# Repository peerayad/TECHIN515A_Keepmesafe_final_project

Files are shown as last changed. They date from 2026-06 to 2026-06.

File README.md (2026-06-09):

# KeepMeSafe — GuardianPod Room Security System

An embedded AI-powered room security system built on the Seeed XIAO ESP32-S3. It detects intruders using a PIR sensor + camera + on-device ML inference (Edge Impulse), then sends an alert with a rotated image to Firebase Realtime Database. A live web dashboard displays alerts in real time.

---

## System Architecture

```
[PIR Sensor] → [ESP32-S3] → [ML Inference (Edge Impulse)]
                   │                      │
              [OV2640 Camera]        Person detected?
                                          │
                              ┌───────────┴───────────┐
                           WiFi ON                 WiFi OFF
                              │                        │
                       [Firebase RTDB]            [SD Card]
                              │
                       [Web Dashboard]
                    keepmesafe-1e248.web.app
```

---

## Hardware Requirements

| Component | Model | Pin |
|---|---|---|
| Microcontroller | Seeed XIAO ESP32-S3 | — |
| Camera | OV2640 (built-in) | — |
| PIR Sensor | Any 3.3V PIR | D0 |
| Buzzer | Active/Passive buzzer | D3 |
| Button A | Tactile button | D6 |
| Button B | Tactile button | D7 |
| OLED Display | SSD1306 128×64 I2C | SDA=D4, SCL=D5 |
| SD Card Module | SPI | CS=D21 |

---

## Software Requirements

### Firmware (ESP32)
- [PlatformIO](https://platformio.org/) with VS Code extension
- Arduino framework for ESP32

### Libraries (auto-installed via `platformio.ini`)
- `Adafruit SSD1306`
- `Adafruit GFX Library`
- `WiFiManager @ ^2.0.17`
- `FirebaseClient @ ^1.5.0`

### Manual Library (place in `/lib`)
- `ML_Camera_inferencing` — Edge Impulse exported library (person detection model)

---

## Firebase Setup

1. Go to [Firebase Console](https://console.firebase.google.com) and create a project (or use existing `keepmesafe-1e248`)
2. Enable **Realtime Database** (start in test mode)
3. Set database rules to allow read/write:
```json
{
  "rules": {
    ".read": true,
    ".write": true
  }
}
```
4. Copy your Firebase config values into `src/main.cpp`:
```cpp
#define FIREBASE_DATABASE_URL "https://your-project-default-rtdb.firebaseio.com"
#define ROOM_ID               "room304"
```

---

## Project Structure

```
keepmesafe_SIT/
├── src/
│   └── main.cpp          # Main firmware
├── lib/
│   └── ML_Camera_inferencing/  # Edge Impulse model library
├── test/
│   └── index.html        # Web dashboard
├── platformio.ini         # PlatformIO config
└── README.md
```

---

## How to Run the Firmware

### 1. Clone / open the project
Open the project folder in VS Code with PlatformIO installed.

### 2. Install dependencies
PlatformIO will auto-install all libraries listed in `platformio.ini` on first build.  
Make sure the Edge Impulse `ML_Camera_inferencing` library is placed in `/lib`.

### 3. Build & Upload
```bash
# Build only
pio run

# Build and upload to device
pio run --target upload

# Open Serial Monitor
pio device monitor --baud 115200
```
Or use the PlatformIO buttons in VS Code (✓ Build / → Upload).

### 4. First Boot — Choose Mode
On startup the OLED will show:
```
Connect WiFi?
A: Connect WiFi
B: SD Card mode
Waiting...
```
- Press **A** → connects to saved WiFi (or opens WiFiManager portal `KeepMeSafe` / password `12345678`)
- Press **B** → offline SD Card mode

---

## How to Run the Web Dashboard

### Option 1 — Local (quick test)
```bash
# In the test/ folder
cd test
python3 -m http.server 8080
```
Then open `http://localhost:8080`

### Option 2 — Firebase Hosting (public URL)
```bash
# Install Firebase CLI
npm install -g firebase-tools

# Login
firebase login

# From project root
firebase init hosting
# → Select project: keepmesafe-1e248
# → Public directory: test
# → Single-page app: No
# → Overwrite index.html: No

# Deploy
firebase deploy --only hosting
```
Live at: `https://keepmesafe-1e248.web.app`

---

## Detection Pipeline

```
PIR triggered
    ↓
Confirm: ≥ 3 triggers in 3 seconds
    ↓
Capture 3 frames (100ms apart)
    ↓ per frame:
  decode JPEG → RGB888
  rotate 90° CCW (portrait)
  resize to EI input size
  auto-contrast normalization
  contrast boost (×1.3)
  Edge Impulse classifier
    ↓
Majority vote: ≥ 2/3 = PERSON
    ↓
Rotate final frame 90° CCW
    ↓
WiFi? → Firebase (base64 JPEG + metadata)
No WiFi? → SD Card (JPEG file)
    ↓
ALARM! — River Flows in You
Press B to cancel
```

---

## Button Controls

| Button | Context | Action |
|---|---|---|
| **A** | Startup | Connect WiFi |
| **B** | Startup | SD Card mode |
| **A** | Standby | Open Settings menu |
| **A** | Settings | Select / navigate |
| **B** | Settings | Next item / exit |
| **B** | Alarm | Cancel alarm immediately |

### Settings Menu
```
SETTINGS
> Mode        ← A to enter
  Sound
A:Select  B:Next/Exit
```
- **Mode** — Switch between WiFi and SD Card mode
- **Sound** — Toggle buzzer ON/OFF

---

## Web Dashboard Features

| Tab | Description |
|---|---|
| **Home** | Live status (SECURED/ALERT), latest snapshot, alert number, time |
| **History** | Last 20 alerts as gallery — click to view full image + time |

---

## Key Configuration

All in `src/main.cpp`:

```cpp
#define PERSON_THRESHOLD  0.5f    // ML confidence threshold (0.0–1.0)
#define CAPTURE_COOLDOWN  10000   // ms between detections
#define ROOM_ID           "room304"

const float alpha = 1.3f;        // Contrast boost multiplier
// personVotes >= 2               // Votes needed out of 3
```

---

## Troubleshooting

| Issue | Cause | Fix |
|---|---|---|
| OLED upside down | Enclosure orientation | `display.setRotation(2)` already applied |
| Firebase not connecting | Rules expired | Set rules `.read/.write = true` |
| Website shows no data | Opened as `file://` | Serve via localhost or Firebase Hosting |
| Image sideways on website | Rotation mismatch | 90° CCW applied automatically in firmware |
| Alert numbers jumping | PIR false triggers | Cooldown reset after each detection |
| Alarm won't stop | — | Press Button B |

---

## License

Built for SIT (School of Information Technology) project — GuardianPod v1.0

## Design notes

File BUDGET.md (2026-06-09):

# Budget Update

| Item | Qty | Unit Price | Total | Source |
|---|---|---|---|---|
| XIAO ESP32S3 Sense (Camera + Mic) | 1 | $23.99 | $23.99 | Seeed |
| MicroSD Card 32GB | 1 | $12.99 | $12.99 | Amazon |
| SD Card Adapter Reader | 1 | $8.89 | $8.89 | Amazon |
| I2S MEMS Microphone | 1 | $13.20 | $13.20 | Adafruit |
| HC-SR501 PIR Sensor | 1 | $3.50 | $3.50 | Amazon |
| SSD1306 OLED 128x64 | 1 | $0.00 | $0.00 | Form Lab |
| Passive Buzzer (D3) | 1 | $0.00 | $0.00 | Form Lab |
| Push Buttons x2 (D6, D7) | 2 | $0.00 | $0.00 | Form Lab |
| Jumper Wires + Breadboard | 1 | $0.00 | $0.00 | Form Lab |
| Female Socket | 1 | $9.98 | $9.98 | Amazon |
| Potentiometer | 1 | $11.99 | $11.99 | Amazon |
| **Total Spent** | | | **$84.57** | |
| **Remaining Budget** | | | **$235.46** | |

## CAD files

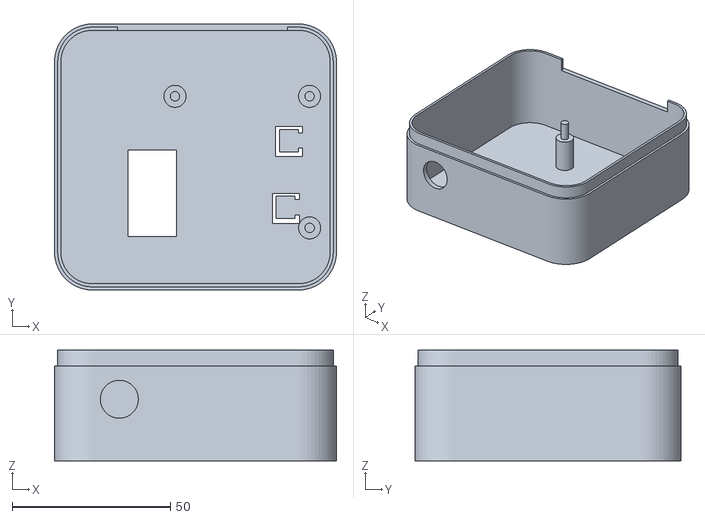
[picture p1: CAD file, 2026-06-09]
body_trial3.stl
89.0 x 84.0 x 35.0

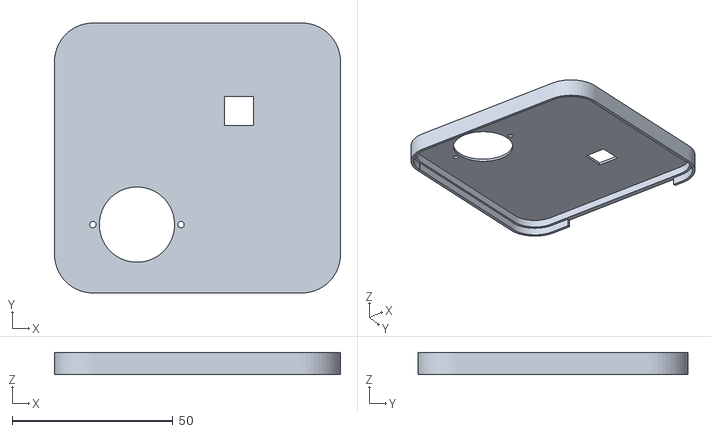
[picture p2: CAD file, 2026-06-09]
lid trial 5.stl
89.0 x 84.0 x 7.00

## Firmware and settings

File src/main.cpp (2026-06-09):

#include <Arduino.h>
#include <Wire.h>
#include <WiFi.h>
#include <WiFiManager.h>
#include <WiFiClientSecure.h>
#include <Adafruit_GFX.h>
#include <Adafruit_SSD1306.h>
#include <FirebaseClient.h>
#include "FS.h"
#include "SD.h"
#include "SPI.h"
#include "esp_camera.h"
#include "esp_task_wdt.h"
#include <ML_Camera_inferencing.h>

#define PERSON_THRESHOLD 0.5f

// ==========================================
// PIN DEFINITIONS
// ==========================================
#define PIR_PIN    D0
#define BUZZER_PIN D3
#define BTN_OK     D6   // กด = ต่อ WiFi
#define BTN_CANCEL D7   // กด = offline SD mode
#define SD_CS      21

// ==========================================
// FIREBASE CONFIG
// ==========================================
#define FIREBASE_DATABASE_URL "https://keepmesafe-1e248-default-rtdb.firebaseio.com"
#define ROOM_ID               "room304"

// ==========================================
// OLED
// ==========================================
#define SCREEN_WIDTH  128
#define SCREEN_HEIGHT  64
#define OLED_ADDRESS  0x3C

// ==========================================
// FORWARD DECLARATIONS
// ==========================================
void buzzShort();
void playAlarm();
void showStandby();
void showMessage(String l1, String l2 = "", String l3 = "");
void showResult(bool isPerson, float confidence, int votes);
void showPersonDetected(int count);
void showSent(int count);
void drawWifiIcon(bool connected);
bool initCamera();
bool initSD();
float runMLInference(camera_fb_t* fb);
void sendAlertToFirebase(int count, camera_fb_t* fb);
void saveToSD(int count, camera_fb_t* fb);
String toBase64(const uint8_t* data, size_t len);
void openSettingsMenu();
bool rotateRGB90CCW(const uint8_t* src, int src_w, int src_h,
                    uint8_t** out_jpg, size_t* out_len);

// ==========================================
// OLED INSTANCE
// ==========================================
Adafruit_SSD1306 display(SCREEN_WIDTH, SCREEN_HEIGHT, &Wire, -1);

// ==========================================
// FIREBASE
// ==========================================
WiFiClientSecure ssl;
DefaultNetwork network;
AsyncClientClass aClient(ssl, getNetwork(network));
FirebaseApp app;
RealtimeDatabase Database;
NoAuth noAuth;

// ==========================================
// CAMERA PINS
// ==========================================
#define PWDN_GPIO_NUM  -1
#define RESET_GPIO_NUM -1
#define XCLK_GPIO_NUM  10
#define SIOD_GPIO_NUM  40
#define SIOC_GPIO_NUM  39
#define Y9_GPIO_NUM    48
#define Y8_GPIO_NUM    11
#define Y7_GPIO_NUM    12
#define Y6_GPIO_NUM    14
#define Y5_GPIO_NUM    16
#define Y4_GPIO_NUM    18
#define Y3_GPIO_NUM    17
#define Y2_GPIO_NUM    15
#define VSYNC_GPIO_NUM 38
#define HREF_GPIO_NUM  47
#define PCLK_GPIO_NUM  13

// ==========================================
// MISSION IMPOSSIBLE THEME
// ==========================================
#define NOTE_B3  247
#define NOTE_C4  262
#define NOTE_CS4 277
#define NOTE_D4  294
#define NOTE_DS4 311
#define NOTE_E4  330
#define NOTE_F4  349
#define NOTE_FS4 370
#define NOTE_G4  392
#define NOTE_GS4 415
#define NOTE_A4  440
#define NOTE_AS4 466
#define NOTE_B4  494
#define NOTE_C5  523
#define NOTE_CS5 554
#define NOTE_D5  587
#define NOTE_DS5 622
#define NOTE_E5  659
#define NOTE_F5  698
#define NOTE_FS5 740
#define NOTE_G5  784
#define NOTE_GS5 831
#define NOTE_A5  880
#define REST     0

// River Flows in You — Yiruma
int riverMelody[] = {
  // Phrase 1
  NOTE_E5,  NOTE_CS5, NOTE_A4,  NOTE_B4,  NOTE_CS5, NOTE_A4,
  NOTE_B4,  NOTE_CS5, NOTE_D5,  NOTE_CS5, NOTE_B4,
  NOTE_A4,  NOTE_CS5, NOTE_E5,  NOTE_A5,
  NOTE_GS5, NOTE_FS5, NOTE_E5,  NOTE_D5,  NOTE_CS5,
  // Phrase 2
  NOTE_E5,  NOTE_CS5, NOTE_A4,  NOTE_B4,  NOTE_CS5, NOTE_A4,
  NOTE_B4,  NOTE_CS5, NOTE_D5,  NOTE_CS5, NOTE_B4,
  NOTE_A4,  NOTE_B4,  NOTE_CS5, NOTE_D5,  NOTE_E5,
  NOTE_A4,
  // Phrase 3
  NOTE_E5,  NOTE_CS5, NOTE_A4,  NOTE_B4,  NOTE_CS5, NOTE_A4,
  NOTE_B4,  NOTE_CS5, NOTE_D5,  NOTE_CS5, NOTE_B4,
  NOTE_A4,  NOTE_CS5, NOTE_E5,  NOTE_A5,
  NOTE_GS5, NOTE_FS5, NOTE_E5,  NOTE_D5,  NOTE_CS5,
  NOTE_B4,  NOTE_A4
};

int riverDurations[] = {
  // Phrase 1
  4, 8, 8, 8, 8, 4,
  4, 8, 8, 4, 4,
  4, 4, 4, 4,
  8, 8, 4, 4, 4,
  // Phrase 2
  4, 8, 8, 8, 8, 4,
  4, 8, 8, 4, 4,
  4, 8, 8, 4, 4,
  2,
  // Phrase 3
  4, 8, 8, 8, 8, 4,
  4, 8, 8, 4, 4,
  4, 4, 4, 4,
  8, 8, 4, 4, 4,
  4, 1
};

int totalNotes = sizeof(riverMelody) / sizeof(riverMelody[0]);

bool soundEnabled = true;  // ประกาศก่อน playAlarm/buzzShort

void playAlarm() {
  // แสดง ALARM! บน OLED
  display.clearDisplay();
  display.setTextColor(SSD1306_WHITE);
  display.drawRect(0, 0, 128, 64, SSD1306_WHITE);
  display.setTextSize(2);
  display.setCursor(22, 8);  display.println("ALARM!");
  display.drawLine(2, 30, 125, 30, SSD1306_WHITE);
  display.setTextSize(1);
  display.setCursor(8, 38);  display.println("Intruder detected!");
  display.setCursor(14, 52); display.println("B: Cancel alarm");
  display.display();

  if (!soundEnabled) {
    // ไม่มีเสียง แต่รอให้กด B เพื่อกลับ standby
    while (digitalRead(BTN_CANCEL) != LOW) delay(50);
    showStandby();
    return;
  }

  for (int i = 0; i < totalNotes; i++) {
    int noteDuration = 1000 / riverDurations[i];
    if (riverMelody[i] == REST) {
      noTone(BUZZER_PIN);
    } else {
      tone(BUZZER_PIN, riverMelody[i], noteDuration);
    }
    unsigned long t = millis();
    while (millis() - t < (unsigned long)(noteDuration * 1.3)) {
      if (digitalRead(BTN_CANCEL) == LOW) {
        noTone(BUZZER_PIN);
        showStandby();
        return;  // กด B → cancel → standby
      }
      delay(10);
    }
    noTone(BUZZER_PIN);
  }
  // เพลงจบเอง → กลับ standby
  showStandby();
}

void buzzShort() {
  if (!soundEnabled) return;
  tone(BUZZER_PIN, 1000, 100);
  delay(150);
  noTone(BUZZER_PIN);
}

// ==========================================
// STATE
// ==========================================
bool          lastPIRState    = false;
int           alertCount      = 0;
bool          firebaseReady   = false;
bool          sdReady         = false;
bool          wifiConnected   = false;
unsigned long lastCaptureTime = 0;
#define CAPTURE_COOLDOWN 10000

// ==========================================
// WIFI ICON (มุมขวาบน)
// ==========================================
void drawWifiIcon(bool connected) {
  // วาด WiFi icon ที่ x=112 y=0 ขนาด 14x8
  if (connected) {
    // arc ใหญ่
    display.drawCircle(119, 8, 7, SSD1306_WHITE);
    // arc กลาง
    display.drawCircle(119, 8, 4, SSD1306_WHITE);
    // จุดตรงกลาง
    display.fillCircle(119, 8, 1, SSD1306_WHITE);
    // ลบครึ่งล่าง arc ออก ให้เหลือแค่ครึ่งบน
    display.fillRect(112, 9, 16, 8, SSD1306_BLACK);
  } else {
    // X แทน WiFi ตอน offline
    display.drawLine(113, 1, 125, 7, SSD1306_WHITE);
    display.drawLine(125, 1, 113, 7, SSD1306_WHITE);
  }
}

// ==========================================
// OLED HELPERS
// ==========================================
void showStandby() {
  display.clearDisplay();
  display.setTextColor(SSD1306_WHITE);
  display.setTextSize(1);
  display.setCursor(0, 0);   display.println("GuardianPod v1.0");
  display.drawLine(0, 10, 127, 10, SSD1306_WHITE);
  display.setCursor(10, 20); display.println("Status: STANDBY");
  display.setCursor(10, 36); display.println("Monitoring...");
  display.setCursor(10, 50);
  if (wifiConnected) {
    display.println("Mode: Firebase");
  } else {
    display.println("Mode: SD Card");
  }
  drawWifiIcon(wifiConnected);
  display.display();
}

void showMessage(String l1, String l2, String l3) {
  display.clearDisplay();
  display.setTextColor(SSD1306_WHITE);
  display.setTextSize(1);
  display.setCursor(0, 8);  display.println(l1);
  display.setCursor(0, 28); display.println(l2);
  display.setCursor(0, 48); display.println(l3);
  drawWifiIcon(wifiConnected);
  display.display();
}

void showResult(bool isPerson, float confidence, int votes) {
  display.clearDisplay();
  display.drawRect(0, 0, 128, 64, SSD1306_WHITE);
  display.setTextColor(SSD1306_WHITE);
  if (isPerson) {
    display.setTextSize(2);
    display.setCursor(14, 6); display.println("INTRUDER!");
  } else {
    display.setTextSize(2);
    display.setCursor(4, 6);  display.println("NO PERSON");
  }
  display.drawLine(2, 28, 126, 28, SSD1306_WHITE);
  display.setTextSize(1);
  display.setCursor(8, 34);
  display.print("Conf: ");
  display.print(confidence * 100, 0);
  display.println("%");
  display.setCursor(8, 46);
  display.print("Votes: ");
  display.print(votes);
  display.println("/3");
  display.display();
}

void showPersonDetected(int count) {
  display.clearDisplay();
  display.drawRect(0, 0, 128, 64, SSD1306_WHITE);
  display.drawRect(2, 2, 124, 60, SSD1306_WHITE);
  display.setTextSize(2);
  display.setTextColor(SSD1306_WHITE);
  display.setCursor(14, 8);  display.println("PERSON!");
  display.drawLine(4, 30, 124, 30, SSD1306_WHITE);
  display.setTextSize(1);
  if (wifiConnected) {
    display.setCursor(8, 36); display.println("Sending Firebase");
  } else {
    display.setCursor(8, 36); display.println("Saving to SD");
  }
  display.setCursor(8, 50); display.print("Alert #"); display.println(count);
  drawWifiIcon(wifiConnected);
  display.display();
}

void showSent(int count) {
  display.clearDisplay();
  display.setTextSize(1);
  display.setTextColor(SSD1306_WHITE);
  if (wifiConnected) {
    display.setCursor(20, 10); display.println("Firebase OK!");
    display.setCursor(28, 28); display.println("Alert sent");
  } else {
    display.setCursor(20, 10); display.println("SD Card OK!");
    display.setCursor(20, 28); display.println("Image saved");
  }
  display.setCursor(8, 46); display.print("Total alerts: "); display.println(count);
  drawWifiIcon(wifiConnected);
  display.display();
  delay(2000);
  showStandby();
}

// ==========================================
// CAMERA INIT
// ==========================================
bool initCamera() {
  camera_config_t cfg;
  cfg.ledc_channel = LEDC_CHANNEL_1;
  cfg.ledc_timer   = LEDC_TIMER_1;
  cfg.pin_d0       = Y2_GPIO_NUM;
  cfg.pin_d1       = Y3_GPIO_NUM;
  cfg.pin_d2       = Y4_GPIO_NUM;
  cfg.pin_d3       = Y5_GPIO_NUM;
  cfg.pin_d4       = Y6_GPIO_NUM;
  cfg.pin_d5       = Y7_GPIO_NUM;
  cfg.pin_d6       = Y8_GPIO_NUM;
  cfg.pin_d7       = Y9_GPIO_NUM;
  cfg.pin_xclk     = XCLK_GPIO_NUM;
  cfg.pin_pclk     = PCLK_GPIO_NUM;
  cfg.pin_vsync    = VSYNC_GPIO_NUM;
  cfg.pin_href     = HREF_GPIO_NUM;
  cfg.pin_sccb_sda = SIOD_GPIO_NUM;
  cfg.pin_sccb_scl = SIOC_GPIO_NUM;
  cfg.pin_pwdn     = PWDN_GPIO_NUM;
  cfg.pin_reset    = RESET_GPIO_NUM;
  cfg.xclk_freq_hz = 20000000;
  cfg.pixel_format = PIXFORMAT_JPEG;
  cfg.frame_size   = FRAMESIZE_SVGA;
  cfg.grab_mode    = CAMERA_GRAB_LATEST;
  cfg.jpeg_quality = 12;
  cfg.fb_count     = 2;
  cfg.fb_location  = CAMERA_FB_IN_PSRAM;

  if (esp_camera_init(&cfg) != ESP_OK) {
    Serial.println("[ERROR] Camera init failed");
    return false;
  }
  sensor_t* s = esp_camera_sensor_get();
  s->set_vflip(s, 0);    // RAW — ไม่ flip
  s->set_hmirror(s, 0);  // RAW — ไม่ mirror
  Serial.println("[OK] Camera ready");
  return true;
}

// ==========================================
// SD CARD INIT
// ==========================================
bool initSD() {
  if (!SD.begin(SD_CS)) {
    Serial.println("[ERROR] SD card mount failed");
    return false;
  }
  if (SD.cardType() == CARD_NONE) {
    Serial.println("[ERROR] No SD card");
    return false;
  }
  if (!SD.exists("/alerts")) SD.mkdir("/alerts");
  Serial.println("[OK] SD card ready");
  return true;
}

// ==========================================
// SAVE TO SD
// ==========================================
void saveToSD(int count, camera_fb_t* fb) {
  if (!sdReady || !fb) return;
  String filename = "/alerts/alert_" + String(count) + ".jpg";
  Serial.printf("[SD] Saving %s...\n", filename.c_str());
  showMessage("Saving to SD...", filename, "");
  File file = SD.open(filename, FILE_WRITE);
  if (!file) { Serial.println("[ERROR] Failed to open file"); return; }
  file.write(fb->buf, fb->len);
  file.close();
  Serial.printf("[SD] Saved %d bytes\n", fb->len);
  File log = SD.open("/alerts/log.txt", FILE_APPEND);
  if (log) {
    log.printf("alert_%d.jpg | %lu ms | %d bytes\n", count, millis(), fb->len);
    log.close();
  }
}

// ==========================================
// BASE64
// ==========================================
static const char b64chars[] =
  "ABCDEFGHIJKLMNOPQRSTUVWXYZabcdefghijklmnopqrstuvwxyz0123456789+/";

String toBase64(const uint8_t* data, size_t len) {
  String result = "";
  result.reserve((len / 3 + 1) * 4 + 4);
  int i = 0;
  uint8_t b3[3], b4[4];
  while (len--) {
    b3[i++] = *data++;
    if (i == 3) {
      b4[0] = (b3[0] & 0xfc) >> 2;
      b4[1] = ((b3[0] & 0x03) << 4) + ((b3[1] & 0xf0) >> 4);
      b4[2] = ((b3[1] & 0x0f) << 2) + ((b3[2] & 0xc0) >> 6);
      b4[3] = b3[2] & 0x3f;
      for (i = 0; i < 4; i++) result += b64chars[b4[i]];
      i = 0;
    }
  }
  if (i) {
    for (int j = i; j < 3; j++) b3[j] = 0;
    b4[0] = (b3[0] & 0xfc) >> 2;
    b4[1] = ((b3[0] & 0x03) << 4) + ((b3[1] & 0xf0) >> 4);
    b4[2] = ((b3[1] & 0x0f) << 2) + ((b3[2] & 0xc0) >> 6);
    for (int j = 0; j < i + 1; j++) result += b64chars[b4[j]];
    while (i++ < 3) result += '=';
  }
  return result;
}

// ==========================================
// JPEG ROTATION (90° CCW) — reuse rgb_buffer from ML
// ==========================================
// หมายเหตุ: เรียกหลัง runMLInference() เท่านั้น (rgb_buffer ต้องมีข้อมูลแล้ว)
bool rotateRGB90CCW(const uint8_t* src, int src_w, int src_h,
                    uint8_t** out_jpg, size_t* out_len) {
  int nw = src_h, nh = src_w;  // 90° CCW: new_w=old_h, new_h=old_w
  size_t rgb_size = (size_t)src_w * src_h * 3;

  uint8_t* rot = (uint8_t*)heap_caps_malloc(rgb_size, MALLOC_CAP_SPIRAM);
  if (!rot) { Serial.println("[ROT] malloc failed"); return false; }

  // CCW: new[row][col] = old[col][old_w - 1 - row]
  for (int row = 0; row < nh; row++) {
    for (int col = 0; col < nw; col++) {
      uint8_t* d = rot + ((size_t)row * nw + col) * 3;
      uint8_t* s = (uint8_t*)src + ((size_t)col * src_w + (src_w - 1 - row)) * 3;
      d[0]=s[0]; d[1]=s[1]; d[2]=s[2];
    }
  }

  *out_jpg = nullptr; *out_len = 0;
  bool ok = fmt2jpg(rot, rgb_size, nw, nh, PIXFORMAT_RGB888, 80, out_jpg, out_len);
  heap_caps_free(rot);
  return ok;
}

// ==========================================
// FIREBASE SEND
// ==========================================
void sendAlertToFirebase(int count, camera_fb_t* fb) {
  if (!firebaseReady) { Serial.println("[WARN] Firebase not ready"); return; }

  String imgBase64 = "";
  if (fb) {
    showMessage("Encoding...", "image to Base64", "");
    imgBase64 = toBase64(fb->buf, fb->len);
    Serial.printf("[Base64] Done — %d chars\n", imgBase64.length());
  }

  String path = "/keepmesafe/" + String(ROOM_ID) + "/alerts/alert_" + String(count);
  String jsonStr = "{";
  jsonStr += "\"status\":\"ALERT\",";
  jsonStr += "\"message\":\"Person detected in room\",";
  jsonStr += "\"alert_num\":" + String(count) + ",";
  jsonStr += "\"timestamp\":{\".sv\":\"timestamp\"},";  // Firebase Server Timestamp
  jsonStr += "\"image\":\"" + imgBase64 + "\"";
  jsonStr += "}";

  showMessage("Sending...", String(jsonStr.length()) + " bytes", "");
  object_t json(jsonStr.c_str());
  Database.set<object_t>(aClient, path, json, [](AsyncResult &aResult) {
    if (aResult.isError()) Serial.println("[Firebase] Error: " + aResult.error().message());
    else Serial.println("[Firebase] Sent OK");
  });
  String latestPath = "/keepmesafe/" + String(ROOM_ID) + "/alerts/latest";
  Database.set<object_t>(aClient, latestPath, json, [](AsyncResult &r) {});
  imgBase64 = ""; jsonStr = "";
}

// ==========================================
// ML INFERENCE
// ==========================================
static uint8_t* rgb_buffer     = nullptr;
static uint8_t* rot_buffer     = nullptr;  // buffer หลัง rotate 90° CCW
static uint8_t* resized_buffer = nullptr;
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
void loop() {
  // Check WiFi status — ถ้าหลุดให้ switch SD mode
  if (wifiConnected) {
    app.loop();

    if (WiFi.status() != WL_CONNECTED) {
      wifiConnected = false;
      firebaseReady = false;
      WiFi.disconnect(true);
      Serial.println("[WARN] WiFi lost → SD mode");
      showMessage("WiFi Lost!", "SD Card mode", "Monitoring...");
      delay(1500);
      showStandby();
    }

    if (!firebaseReady && app.ready()) {
      firebaseReady = true;
      Serial.println("[OK] Firebase ready (retry)");
    }
  }

  // A button → Settings menu
  if (digitalRead(BTN_OK) == LOW) {
    delay(50);
    if (digitalRead(BTN_OK) == LOW) {
      openSettingsMenu();
      showStandby();
    }
  }

  bool pirState = digitalRead(PIR_PIN);

  if (pirState == HIGH &&
      millis() - lastCaptureTime >= CAPTURE_COOLDOWN) {

    Serial.println("[PIR] Motion detected! Counting triggers for 3s...");
    showMessage("Motion!", "Confirming...", "Wait 3s");

    int triggerCount = 0;
    unsigned long startTime = millis();
    while (millis() - startTime < 3000) {
      if (digitalRead(PIR_PIN) == HIGH) triggerCount++;
      delay(200);
    }

    Serial.printf("[PIR] Trigger count: %d\n", triggerCount);

    if (triggerCount >= 3) {
      lastCaptureTime = millis();
      buzzShort();

      Serial.println("[PIR] Confirmed! Running ML...");
      showMessage("ML Running...", "Analyzing...", "Please wait");

      camera_fb_t* fb = esp_camera_fb_get();
      if (!fb) {
        Serial.println("[ERROR] Capture failed");
        showMessage("Camera ERROR", "Capture failed", "");
      } else {
        Serial.printf("[Camera] %d bytes\n", fb->len);

        int   personVotes     = 0;
        float totalConfidence = 0.0f;

        for (int v = 0; v < 3; v++) {
          camera_fb_t* vfb = esp_camera_fb_get();
          if (!vfb) {
            Serial.printf("[ML] Vote %d: capture failed\n", v + 1);
            // แสดงบน OLED
            display.clearDisplay();
            display.setTextSize(1);
            display.setTextColor(SSD1306_WHITE);
            display.setCursor(0, 0);  display.println("ML Voting...");
            display.drawLine(0, 10, 127, 10, SSD1306_WHITE);
            display.setCursor(0, 16); display.printf("Vote %d/3", v + 1);
            display.setCursor(0, 30); display.println("Capture failed");
            display.display();
            continue;
          }
          float conf = runMLInference(vfb);
          esp_camera_fb_return(vfb);
          totalConfidence += conf;
          if (conf >= PERSON_THRESHOLD) personVotes++;

          // แสดงผล vote บน OLED เหมือน Serial
          Serial.printf("[ML] Vote %d: %.2f\n", v + 1, conf);
          display.clearDisplay();
          display.setTextSize(1);
          display.setTextColor(SSD1306_WHITE);
          display.setCursor(0, 0);  display.println("ML Voting...");
          display.drawLine(0, 10, 127, 10, SSD1306_WHITE);
          display.setCursor(0, 16); display.printf("Vote %d/3", v + 1);
          display.setCursor(0, 28); display.printf("Person: %.0f%%", conf * 100);
          display.setCursor(0, 40); display.printf("Votes:  %d/3", personVotes);
          display.setCursor(0, 52); display.printf("Avg:    %.0f%%", (totalConfidence / (v + 1)) * 100);
          display.display();

          delay(100);
        }

        float avgConfidence = totalConfidence / 3.0f;
        bool isPerson = (personVotes >= 2);

        Serial.printf("[ML] Votes: %d/3 | Avg: %.2f → %s\n",
          personVotes, avgConfidence, isPerson ? "PERSON" : "NO PERSON");

        if (isPerson) {
          alertCount++;  // นับเฉพาะตอนที่ detect person จริงๆ
          showPersonDetected(alertCount);
          // Rotate 90° CCW โดยใช้ rgb_buffer ที่ ML decode ไว้แล้ว
          showMessage("Rotating...", "90 CCW", "");
          uint8_t* rotJpg = nullptr;
          size_t   rotLen = 0;
          bool rotOk = rotateRGB90CCW(rgb_buffer, 800, 600, &rotJpg, &rotLen);

          camera_fb_t rotFb;
          camera_fb_t* sendFb = fb;  // fallback
          if (rotOk && rotJpg) {
            rotFb.buf = rotJpg; rotFb.len = rotLen;
            rotFb.width = 600; rotFb.height = 800;
            rotFb.format = PIXFORMAT_JPEG;
            sendFb = &rotFb;
          }

          if (wifiConnected && firebaseReady) {
            Serial.println("[OK] Sending to Firebase");
            sendAlertToFirebase(alertCount, sendFb);
          } else {
            Serial.println("[OK] Saving to SD card");
            saveToSD(alertCount, sendFb);
          }
          if (rotJpg) free(rotJpg);
          lastCaptureTime = millis();  // reset cooldown หลังส่งเสร็จ ป้องกัน re-trigger
          showSent(alertCount);
          playAlarm();
        } else {
          showResult(isPerson, avgConfidence, personVotes);
          delay(3000);
          showStandby();
        }

        esp_camera_fb_return(fb);
      }
    } else {
      Serial.println("[PIR] False trigger — ignored");
      showStandby();
    }
  }

  lastPIRState = pirState;
  delay(50);
}

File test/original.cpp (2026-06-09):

#include <Arduino.h>
#include <Wire.h>
#include <WiFi.h>
#include <WiFiManager.h>
#include <WiFiClientSecure.h>
#include <Adafruit_GFX.h>
#include <Adafruit_SSD1306.h>
#include <FirebaseClient.h>
#include "esp_camera.h"
#include "esp_task_wdt.h"

// Edge Impulse ML
#include <ML_Camera_inferencing.h>

// ==========================================
// PIN DEFINITIONS
// ==========================================
#define PIR_PIN    D9
#define LED_PIN    D8
#define BUZZER_PIN D0
#define SDA_PIN    D4
#define SCL_PIN    D5

// ==========================================
// FIREBASE CONFIG
// ==========================================
#define FIREBASE_DATABASE_URL "https://keepmesafe-1e248-default-rtdb.firebaseio.com"
#define ROOM_ID               "room304"

// ==========================================
// OLED
// ==========================================
#define SCREEN_WIDTH  128
#define SCREEN_HEIGHT  64
#define OLED_ADDRESS  0x3C
Adafruit_SSD1306 display(SCREEN_WIDTH, SCREEN_HEIGHT, &Wire, -1);

// ==========================================
// FIREBASE
// ==========================================
WiFiClientSecure ssl;
DefaultNetwork network;
AsyncClientClass aClient(ssl, getNetwork(network));
FirebaseApp app;
RealtimeDatabase Database;
NoAuth noAuth;

// ==========================================
// CAMERA PINS (XIAO ESP32S3 Sense)
// ==========================================
#define PWDN_GPIO_NUM  -1
#define RESET_GPIO_NUM -1
#define XCLK_GPIO_NUM  10
#define SIOD_GPIO_NUM  40
#define SIOC_GPIO_NUM  39
#define Y9_GPIO_NUM    48
#define Y8_GPIO_NUM    11
#define Y7_GPIO_NUM    12
#define Y6_GPIO_NUM    14
#define Y5_GPIO_NUM    16
#define Y4_GPIO_NUM    18
#define Y3_GPIO_NUM    17
#define Y2_GPIO_NUM    15
#define VSYNC_GPIO_NUM 38
#define HREF_GPIO_NUM  47
#define PCLK_GPIO_NUM  13

// ==========================================
// STATE
// ==========================================
bool          lastPIRState    = false;
int           alertCount      = 0;
bool          firebaseReady   = false;
unsigned long lastCaptureTime = 0;
#define CAPTURE_COOLDOWN 10000

volatile bool alarmLED        = false;
volatile bool playMelody      = false;
TaskHandle_t  blinkTaskHandle = NULL;

// ==========================================
// JINGLE BELLS MELODY
// ==========================================
#define NOTE_C4  262
#define NOTE_D4  294
#define NOTE_E4  330
#define NOTE_F4  349
#define NOTE_G4  392
#define NOTE_A4  440
#define NOTE_B4  494
#define NOTE_C5  523

const int jinglNotes[] = {
  NOTE_E4, NOTE_E4, NOTE_E4,
  NOTE_E4, NOTE_E4, NOTE_E4,
  NOTE_E4, NOTE_G4, NOTE_C4, NOTE_D4, NOTE_E4,
  NOTE_F4, NOTE_F4, NOTE_F4, NOTE_F4,
  NOTE_F4, NOTE_E4, NOTE_E4, NOTE_E4,
  NOTE_E4, NOTE_D4, NOTE_D4, NOTE_E4, NOTE_D4, NOTE_G4,
  NOTE_E4, NOTE_E4, NOTE_E4,
  NOTE_E4, NOTE_E4, NOTE_E4,
  NOTE_E4, NOTE_G4, NOTE_C4, NOTE_D4, NOTE_E4,
  NOTE_F4, NOTE_F4, NOTE_F4, NOTE_F4,
  NOTE_F4, NOTE_E4, NOTE_E4, NOTE_E4,
  NOTE_G4, NOTE_G4, NOTE_F4, NOTE_D4, NOTE_C4
};

const int jinglDur[] = {
  200, 200, 400,
  200, 200, 400,
  200, 200, 200, 200, 800,
  200, 200, 200, 200,
  200, 200, 200, 200,
  200, 200, 200, 200, 200, 800,
  200, 200, 400,
  200, 200, 400,
  200, 200, 200, 200, 800,
  200, 200, 200, 200,
  200, 200, 200, 200,
  200, 200, 200, 200, 800
};

void blinkTask(void* param) {
  int noteIndex = 0;
  int noteLen   = sizeof(jinglNotes) / sizeof(jinglNotes[0]);
  while (true) {
    if (alarmLED) {
      digitalWrite(LED_PIN, HIGH);
      vTaskDelay(300 / portTICK_PERIOD_MS);
      digitalWrite(LED_PIN, LOW);
      vTaskDelay(300 / portTICK_PERIOD_MS);
    } else if (playMelody) {
      if (noteIndex < noteLen) {
        tone(BUZZER_PIN, jinglNotes[noteIndex], jinglDur[noteIndex]);
        digitalWrite(LED_PIN, HIGH);
        vTaskDelay((int)(jinglDur[noteIndex] * 1.1) / portTICK_PERIOD_MS);
        noTone(BUZZER_PIN);
        digitalWrite(LED_PIN, LOW);
        noteIndex++;
      } else {
        playMelody = false;
        noteIndex  = 0;
        digitalWrite(LED_PIN, LOW);
        digitalWrite(BUZZER_PIN, LOW);
      }
    } else {
      noteIndex = 0;
      digitalWrite(LED_PIN, LOW);
      digitalWrite(BUZZER_PIN, LOW);
      vTaskDelay(100 / portTICK_PERIOD_MS);
    }
  }
}

// ==========================================
// OLED HELPERS
// ==========================================
void showStandby() {
  display.clearDisplay();
  display.setTextColor(SSD1306_WHITE);
  display.setTextSize(1);
  display.setCursor(20, 0);  display.println("GuardianPod v1.0");
  display.drawLine(0, 10, 127, 10, SSD1306_WHITE);
  display.setCursor(10, 20); display.println("Status: STANDBY");
  display.setCursor(10, 36); display.println("Monitoring...");
  display.display();
}

void showMessage(String l1, String l2 = "", String l3 = "") {
  display.clearDisplay();
  display.setTextColor(SSD1306_WHITE);
  display.setTextSize(1);
  display.setCursor(0, 8);  display.println(l1);
  display.setCursor(0, 28); display.println(l2);
  display.setCursor(0, 48); display.println(l3);
  display.display();
}

void showPersonDetected(int count) {
  display.clearDisplay();
  display.drawRect(0, 0, 128, 64, SSD1306_WHITE);
  display.drawRect(2, 2, 124, 60, SSD1306_WHITE);
  display.setTextSize(2);
  display.setTextColor(SSD1306_WHITE);
  display.setCursor(14, 8);  display.println("PERSON!");
  display.drawLine(4, 30, 124, 30, SSD1306_WHITE);
  display.setTextSize(1);
  display.setCursor(8, 36);  display.println("Sending alert...");
  display.setCursor(8, 50);  display.print("Alert #"); display.println(count);
  display.display();
}

void showSent(int count) {
  display.clearDisplay();
  display.setTextSize(1);
  display.setTextColor(SSD1306_WHITE);
  display.setCursor(20, 10); display.println("Firebase OK!");
  display.setCursor(28, 28); display.println("Alert sent");
  display.setCursor(8,  46); display.print("Total alerts: "); display.println(count);
  display.display();
  delay(2000);
  showStandby();
}
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
